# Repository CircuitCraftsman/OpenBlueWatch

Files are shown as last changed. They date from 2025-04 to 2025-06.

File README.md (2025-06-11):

# OpenBlueWatch
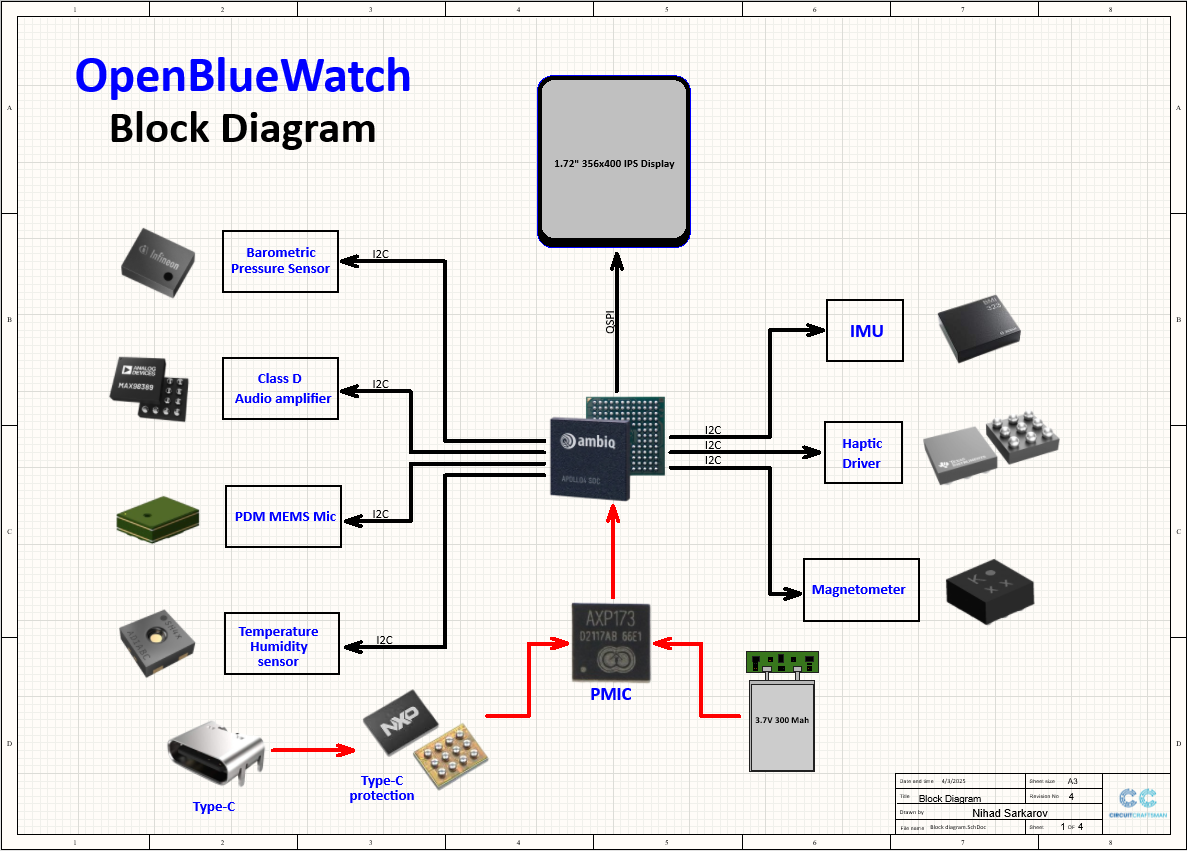
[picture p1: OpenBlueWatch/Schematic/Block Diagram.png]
OpenBlueWatch


Open-source smart watch design in Altium Designer. The smartwatch is based on the Apollo 4 Blue Plus SoC. It incorporates a pressure sensor, an inertial measurement unit, a magnetometer, a temperature and humidity sensor, a MEMS microphone, a haptic driver, and a Class D amplifier. Additionally, power management is based on the AXP173 PMIC. The device can be programmed with the JLINK adapter. 

# Contents
- [Used Tools](#Used-Tools)
- [Specs](#Specs)
- [Schematic](#Schematic)
- [Layout](#Layout)
- [3D Views](#3D-Views)
- [Future Work](#Future-Work)

# Used Tools
    
- Altium Designer

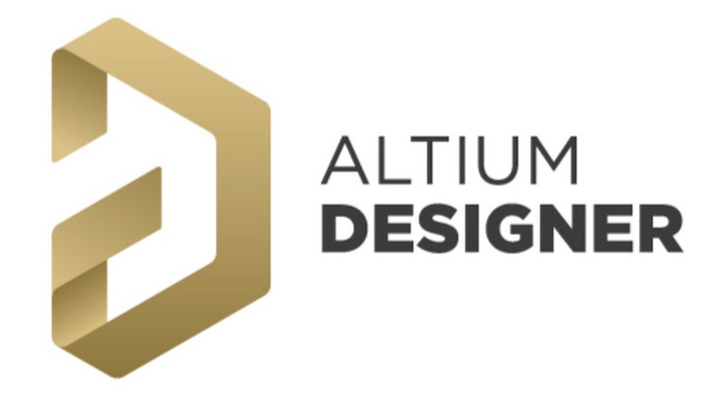
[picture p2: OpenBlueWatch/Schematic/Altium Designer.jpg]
Altium Designer


Altium Designer (AD) is a software package for printed circuit board (PCB) design and electronic design automation. It was developed by the American software company Altium Limited. Altium Designer was formerly known as Protel.

- Saturn PCB Toolkit

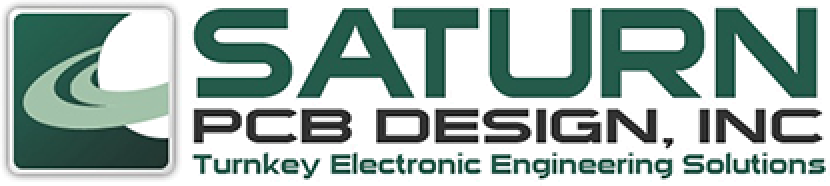
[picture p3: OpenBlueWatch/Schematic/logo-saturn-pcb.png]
Saturn PCB Toolkit


The Saturn PCB Toolkit is the best freeware resource for PCB-related calculations. It incorporates many features that PCB designers and engineers regularly need, like the current capacity of a PCB trace, via current, differential pairs, and much more.

# Specs

  • Bluetooth Low Energy (BLE) 5.4
  
  • Real-time Time Clock
  
  • Environmental sensors
  
  • Smart Power Management
  
  • Type-C charger

# Schematic 

**MCU**

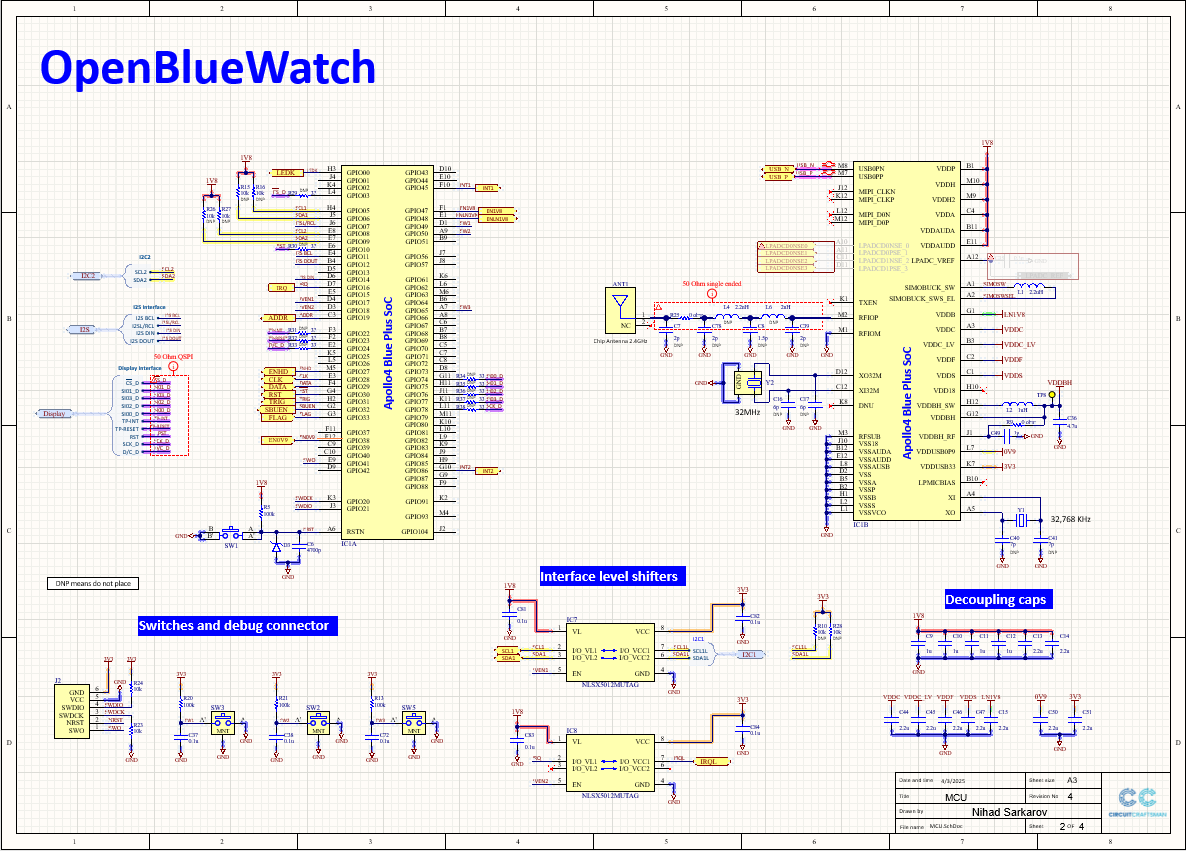
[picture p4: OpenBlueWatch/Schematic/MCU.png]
MCU


**Sensors**

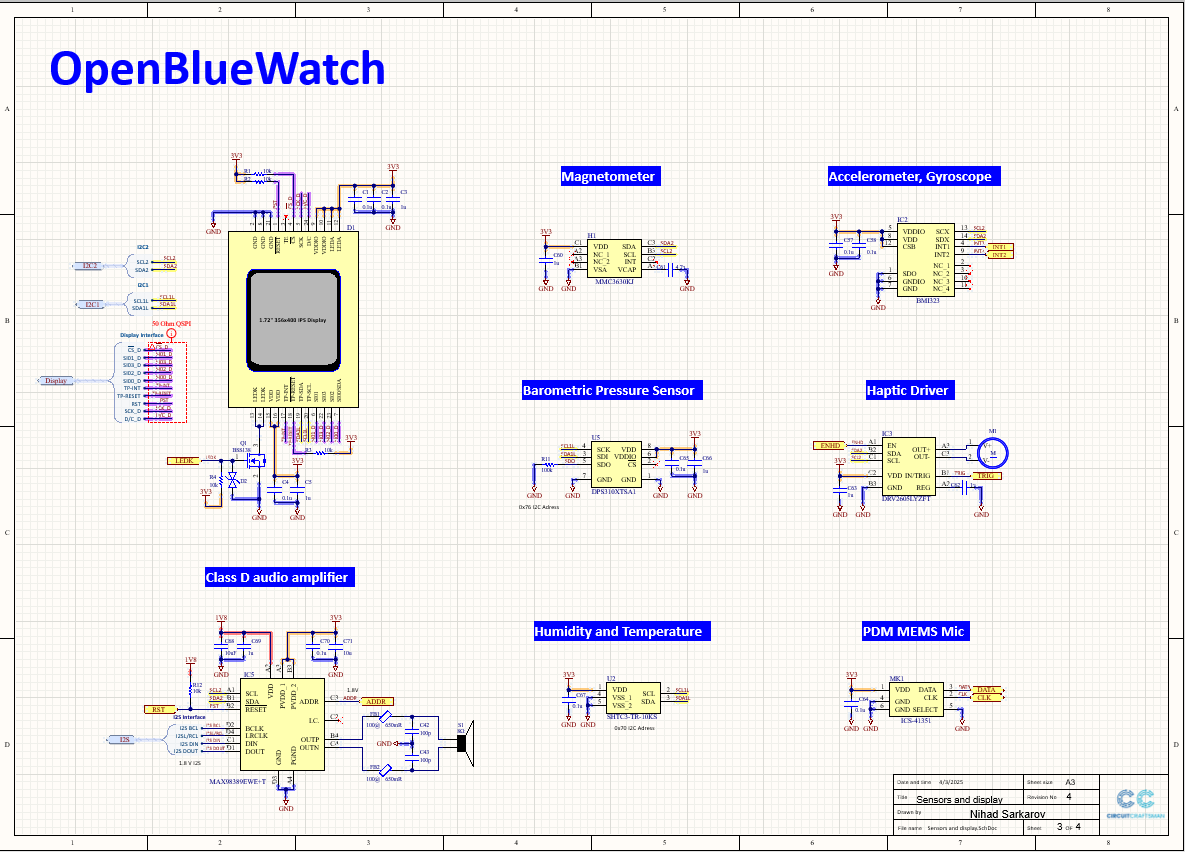
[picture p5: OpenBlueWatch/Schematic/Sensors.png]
Sensors


**Power**

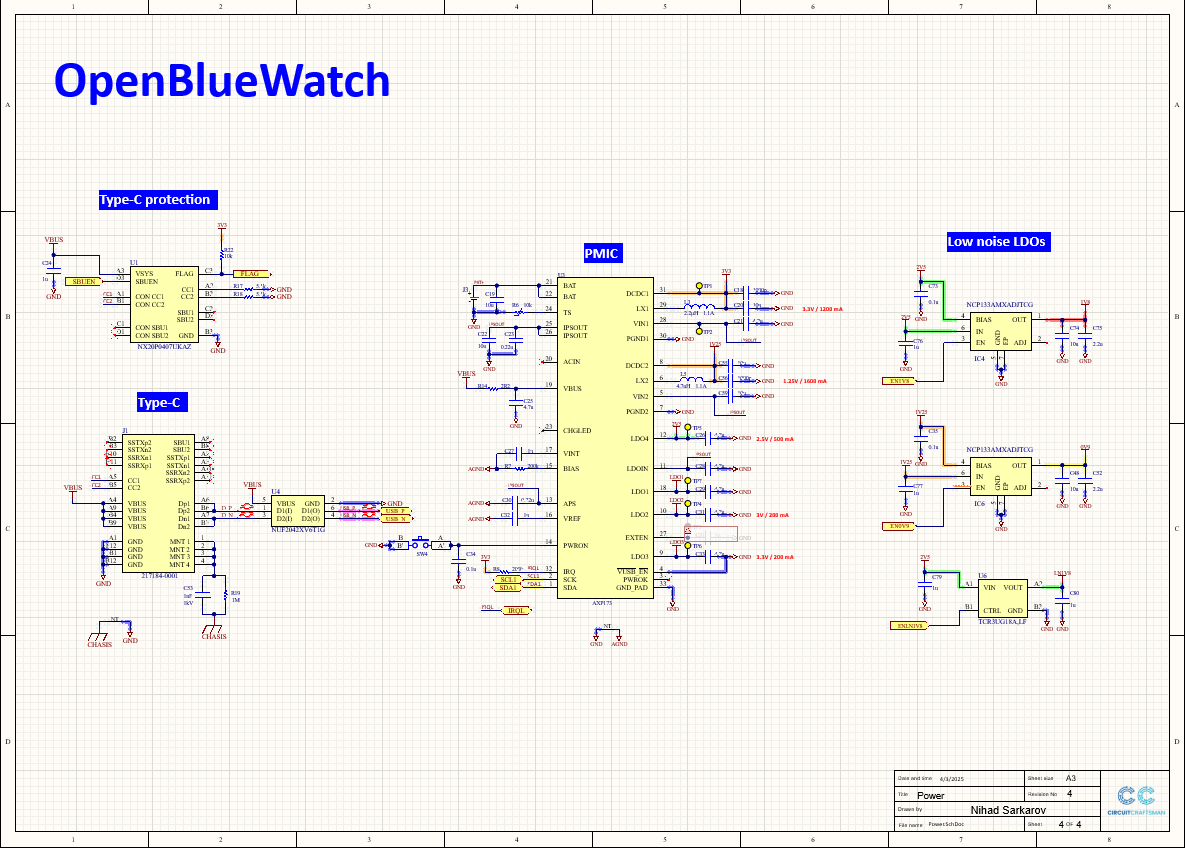
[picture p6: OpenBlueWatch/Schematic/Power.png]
Power


# Layout

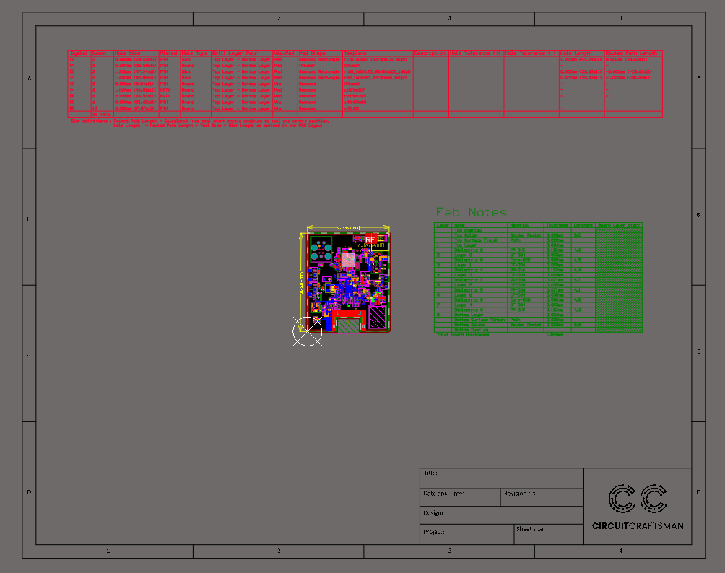
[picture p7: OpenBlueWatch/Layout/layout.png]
Layout


# 3D views

**Front View (Version 2)**

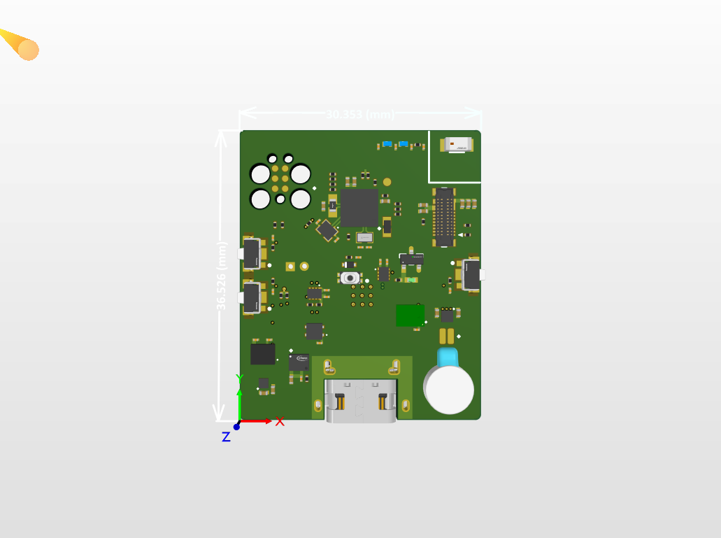
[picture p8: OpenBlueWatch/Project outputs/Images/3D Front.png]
Front


**Front View (Version 1)**

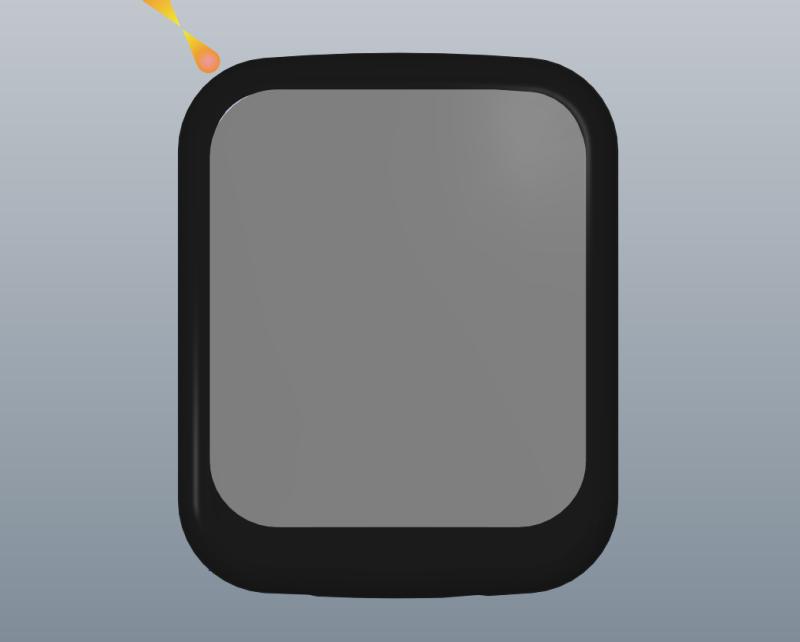
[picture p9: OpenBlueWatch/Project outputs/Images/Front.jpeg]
Front (Version 1)


**Front without display (Version 1)**

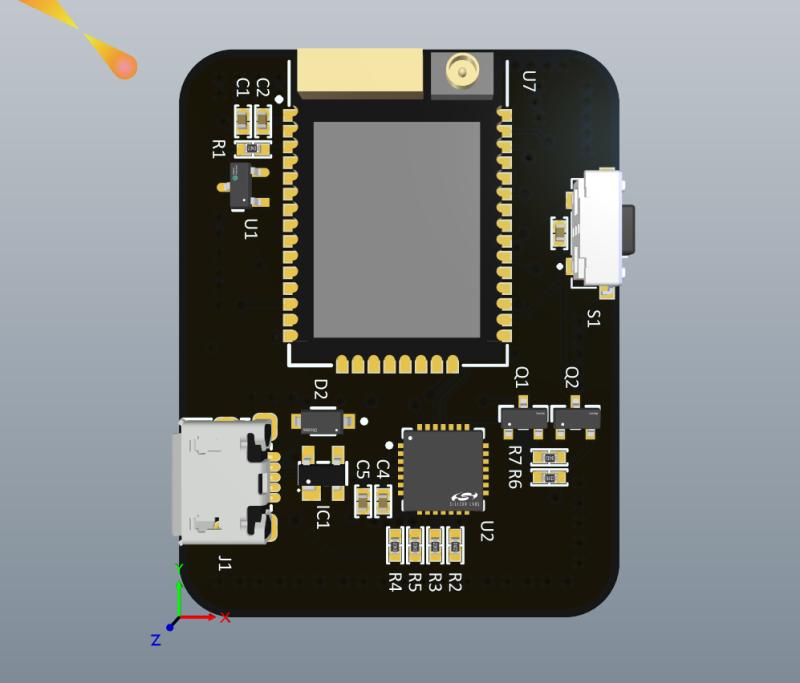
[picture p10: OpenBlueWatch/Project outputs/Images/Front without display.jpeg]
Front without display (Version 1)


**Back (Version 1)**

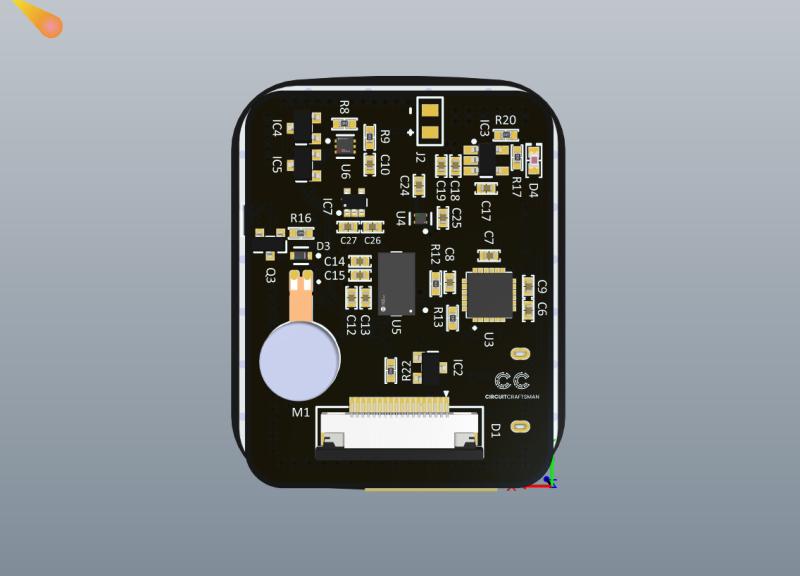
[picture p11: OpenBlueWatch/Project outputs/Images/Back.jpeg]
Back (Version 1)


# Future Work

  • The device will be designed using another layer stackup
  
  • NFC feature will be added
  
  • Another power management solution will be used

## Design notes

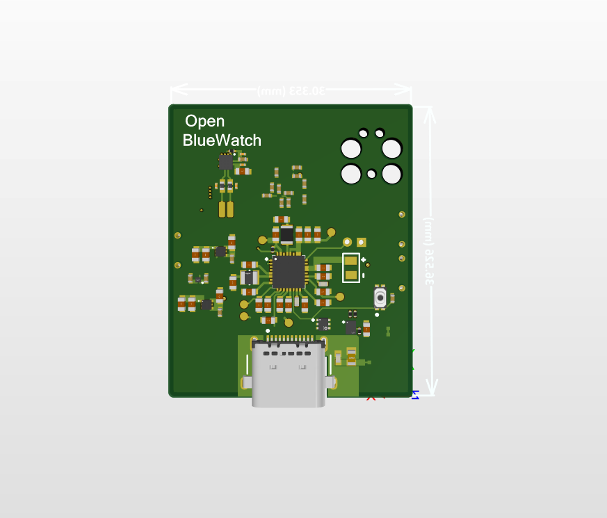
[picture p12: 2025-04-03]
OpenBlueWatch/Project outputs/Images/3D Back.png

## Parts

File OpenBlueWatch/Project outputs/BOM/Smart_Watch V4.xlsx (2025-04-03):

Comment | Description | Designator | Footprint | LibRef | Quantity
2450AT18A0100001E | 2450AT18A0100001E Antenna Chip 2.4GHZ Miniature | ANT1 | FP-2450AT18A0100001E-MFG | CMP-00849-122784405-1 | 1
CC0402KRX7R7BB104 | CAP CER X7R 0402 | C1, C2, C3, C4, C5, C9, C10, C11, C12, C13, C14, C15, C34, C35, C36, C44, C45, C46, C47, C49, C50, C51, C60, C61, C62, C63, C66, C68, C73, C79, C80 | FP-CC0402-IPC_C | CMP-03422-000048-1 | 31
CC0201KRX7R8BB102 | CAP CER X7R 0201 | C6, C7, C8, C16, C17, C37, C38, C39, C40, C41, C42, C43, C57, C58, C64, C65, C67, C69, C70, C72, C78, C81, C82, C83, C84 | FP-CC0201-BA-MFG | CMP-03422-000456-1 | 25
C1608X7R1E105K080AB | Multilayer Ceramic Capacitors 1μF ±10% 25V X7R SMD 0603 | C18, C19, C20, C21, C22, C23, C24, C25, C26, C27, C28, C29, C30, C31, C32, C33, C48, C52, C55, C56, C59, C71, C74, C75, C76, C77 | FP-C1608-080-0_1-MFG | CMP-08246-005723-1 | 26
C0603V102KDRAC7867 | 1000 pF ±10% 1000V (1kV) Ceramic Capacitor X7R 0603 (1608 Metric) | C53 | CAPC1608X90N | C0603V102KDRAC7867 | 1
1.72" 356x400 IPS Display | B2B Connector 24 Pin – In Cell Touch | D1 | CONN-SMD_24P-P0.40_X0400FVS-24-LPSN | 1.72" 356*400 IPS Display | 1
PGB1010402KR | TVS DIODE 12V 250V 0402 | D2 | FP-PGB1-0402-IPC_A | CMP-2000-05189-2 | 1
PESD5V0X1UB,135 | Ultra low capacitance unidirectional ElectroStatic Discharge (ESD) protection diode in a SOD523 (SC-79) ultra small and flat lead Surface-Mounted Device (SMD) plastic package designed to protect one signal line from the damage caused by ESD and other transients.<p> <author>AAL Eindhoven MK</author><hr><p> <img src=http://www.nxp.com/img/NXP_logo.png> | D3 | SOD523 | PESD5V0X1UB,135 | 1
BLM15AG102SN1D | Chip Ferrite Bead, 0402, 1000Ω @ 100MHz, 0.65Ω, 25%, 300mA | FB1, FB2 | FP-BLM15-0_05-IPC_A | CMP-0686-00181-5 | 2
MMC3630KJ | MAGNETIC SENSOR 3-AXIS 1.2X1.2MM | H1 | BGA8C40P3X3_120X120X57 | MMC3630KJ | 1
AMA4B2KP-KXR | ARM® Cortex®-M4F System On Chip (SOC) IC Apollo4 Blue Plus 192MHz 131-BGA (4.7x4.7) | IC1 | BGA131C35P12X12_470X470X90 | AMA4B2KP-KXR | 1
BMI323 | Accelerometer, Gyroscope, 6 Axis Sensor I2C, I3C, SPI Output | IC2 | BMI323 | BMI323 | 1
DRV2605LYZFT | Motor Driver Power MOSFET I2C 9-DSBGA | IC3 | BGA9C50P3X3_144X144X62 | DRV2605LYZFT | 1
NCP133AMXADJTCG | Integrated Circuit | IC4, IC6 | NCP133AMX110TCG | NCP133AMXADJTCG | 2
MAX98389EWE+T | Amplifier IC 1-Channel (Mono) Class D 16-WLP (1.64x1.79) | IC5 | BGA16C40P4X4_179X164X69 | MAX98389EWE+T | 1
NLSX5012MUTAG | Voltage Level Translator Bidirectional 1 Circuit 2 Channel 100Mbps 8-UDFN (1.8x1.2) | IC7, IC8 | NLSX5012MUTAG | NLSX5012MUTAG | 2
217184-0001 | MID-MOUNT DUAL ROWS SMT 24POS -T | J1 | FP-217184-0001-MFG | CMP-04767-000027-1 | 1
8.06.16_J-LINK_6-PIN_NEEDLE_ADAPTER | J-LINK 6-PIN NEEDLE ADAPTER | J2 | SEGGER_8.06.16_J-LINK_6-PIN_NEEDLE_ADAPTER | 8.06.16_J-LINK_6-PIN_NEEDLE_ADAPTER | 1
Battery connector | JST-PH 2.0MM | J3 | JST-PH 2.0MM | Battery connector | 1
MBKK1608T2R2M | Ind Power Wirewound 2.2uH 20% 1MHz Metal 520mA 0603 Embossed T/R | L1 | INDC1608X100N | MBKK1608T2R2M | 1
DFE18SAN1R0ME0L | FIXED IND 1UH 1.6A 144 MOHM SMD | L2 | FP-DFE18SAN_E0-IPC_A | CMP-06042-016331-1 | 1
BRC2012T2R2MD | Wire-Wound Chip Power Inductor, 2.2 uH, +/- 20%, -40 to 105 degC, 2-Pin SMD (0805), RoHS, Tape and Reel | L3 | INDC2013X140X50LL20T20 | CMP-2000-05964-1 | 1
LQW15AN3N9B00D | Wire Wound RF Inductor 3.9nH ±0.1nH 750mA 0.07Ω 0402 (1005) | L4, L6 | FP-LQW15AN_00-W0_6-0_1-MFG | CMP-06042-000827-1 | 2
LQM2MPN4R7MG0L | Multilayer Type Inductor for Power Lines, 0806 (2016), 4.7μH, 20%, 0.175Ω, 1.1A | L5 | FP-LQM2MPN_G0-MFG | CMP-06042-016483-1 | 1
NFP-WS0625 | 6mm Brushless Coin Vibration Motor 2.5mm Type Motor | M1 | NFP-WS0625 | NFP-WS0625 | 1
ICS-41351 | 50 Hz ~ 20 kHz Digital, PDM Microphone MEMS (Silicon) Omnidirectional (-26dB ±1dB @ 94dB SPL) Solder Pads | MK1 | MIC_ICS-41351 | ICS-41351 | 1
BSS138 | MOSFET N-CH 50V 220MA SOT-23 | Q1 | FP-318-08-IPC_B | CMP-07173-000101-1 | 1
CRCW02010000Z0ED | Chip Resistor, 0 Ohm, 0.05 W, -55 to 155 degC, 0201 (0603 Metric), RoHS, Tape and Reel | R1, R2, R3, R4, R5, R8, R9, R10, R11, R12, R13, R15, R16, R17, R18, R20, R21, R22, R23, R24, R25, R26, R27, R28, R29, R30, R31, R32, R33, R34, R35, R36, R37, R38 | RESC0603X28X15LL5T05 | CMP-2004-00001-2 | 34
NTSD1XH103FPB30 | NTC Thermistors 10kΩ ±1% Current 0.12mA Radial | R6 | FP-NTSD1_FPB30-MFG | CMP-06022-000009-1 | 1
CRCW040222R0FKED |  | R7, R14 | RESC1005X40X25LL05T05 | CMP-2002-08382-1 | 2
ERJ-2GEJ105X |  | R19 | RESC1005X40X25ML05T05 | CMP-1011-00146-2 | 1
CMS-15118D-L100 | 8 Ohms Low Profile Speaker 700 mW 425 Hz ~ 10 kHz Top Rectangular | S1 | CMS-15118D-L100 | CMS-15118D-L100 | 1
EVP-BB2A9B000 | SWITCH TACTILE SPST-NO 0.02A 15V | SW1, SW4 | FP-EVP-BB2A9B000-MFG | CMP-05618-000013-1 | 2
EVP-AKE31A | 3.8MM X 1.9MM / 1.6N / 0.12MM ST | SW2, SW3, SW5 | FP-EVP-AKE31A-MFG | CMP-05618-000005-1 | 3
Test point | 1mm x 1mm round pad for testing purposes | TP1, TP2, TP4, TP5, TP6, TP7, TP8 | Test point | Test point | 7
NX20P0407UKAZ | USB TYPE-C CC1/2 SBU1/2 PROT IC | U1 | FP-SOT1390-7-IPC_A | CMP-10136-000007-1 | 1
SHTC3-TR-10KS | Humidity, Temperature 0 ~ 100% RH I2C ±2% RH 8 s Surface Mount | U2 | SHTC3TR10KS | SHTC3-TR-10KS | 1
AXP173 | PMIC | U3 | QFN40P400X400X55-33N | AXP173 | 1
NUF2042XV6T1G | RC (Pi) EMI Filter 2nd Order Low Pass 2 Channel R = 22Ohms, C = 42pF (Total) SOT-563, SOT-666 | U4 | FP-463A-MFG | CMP-1066-00027-2 | 1
DPS310XTSA1 | Pressure Sensor 4.35PSI ~ 17.4PSI (30kPa ~ 120kPa) Absolute 24 b 8-VFLGA | U5 | FP-PG-VLGA-8-MFG | CMP-32885-000002-2 | 1
TCR3UG18A,LF | IC REG LINEAR 1.8V 300MA 4WCSP-F | U6 | FP-WCSP4F-IPC_C | CMP-35871-000003-1 | 1
ABS06-32.768KHZ-1-T | CRYSTAL 32.7680KHZ 12.5PF SMD | Y1 | FP-ABS06-MFG | CMP-27762-012387-2 | 1
CX2016DB32000D0WZRC1 | 32 MHz ±25ppm Crystal 8pF 60 Ohms 4-SMD, No Lead | Y2 | CX2016DB32000D0WZRC1 | CX2016DB32000D0WZRC1 | 1

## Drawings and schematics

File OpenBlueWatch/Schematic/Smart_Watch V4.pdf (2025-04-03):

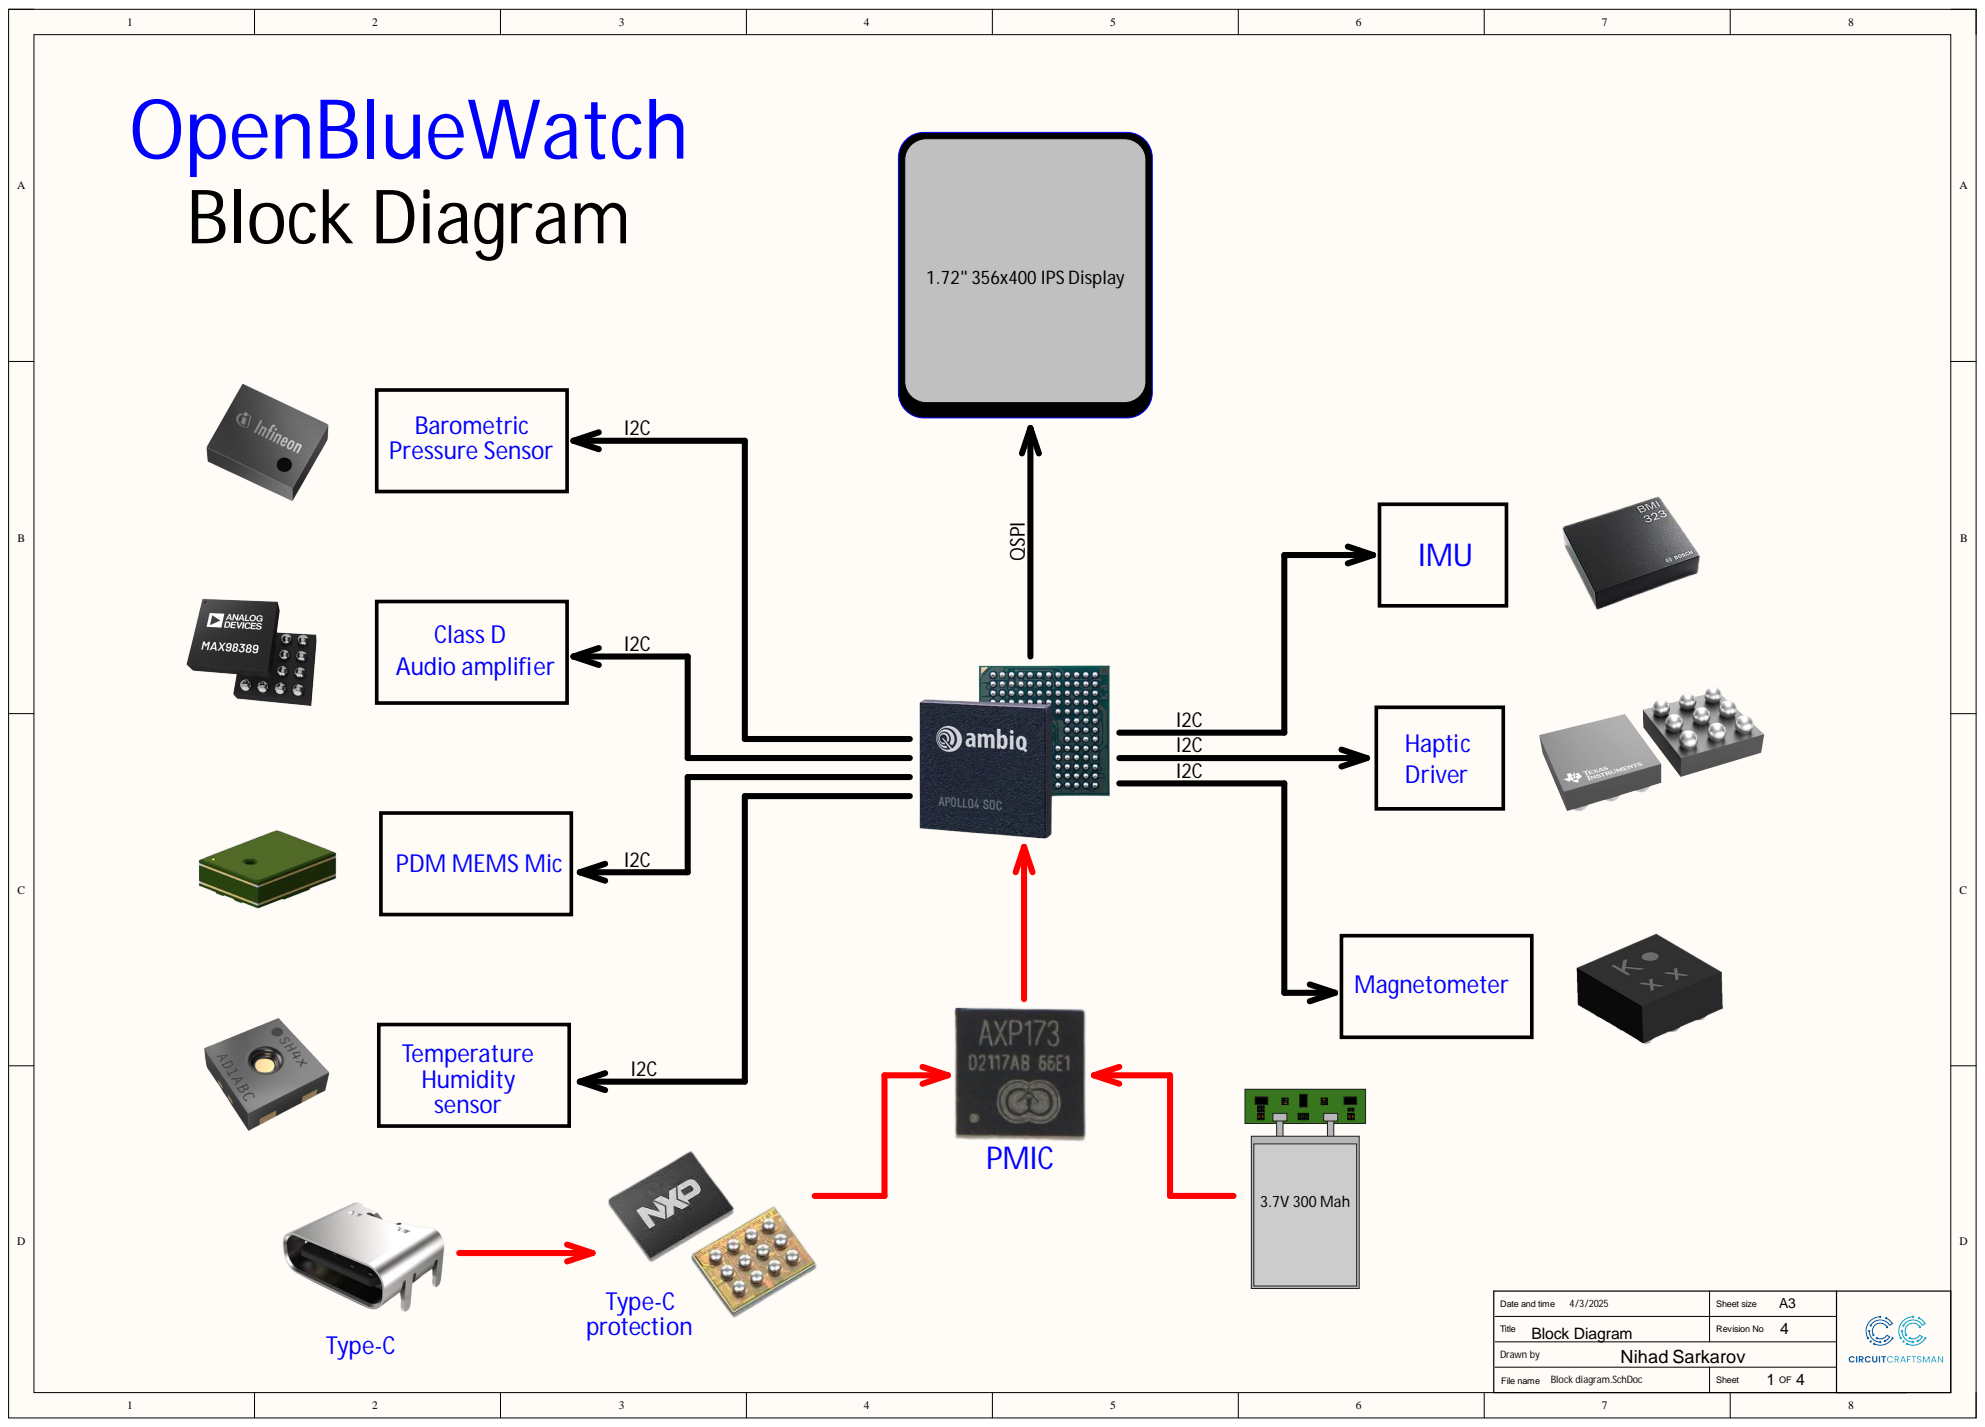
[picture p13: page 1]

Date and time 4/3/2025 | Sheet size A3

Block Diagram Title | 4 Revision No

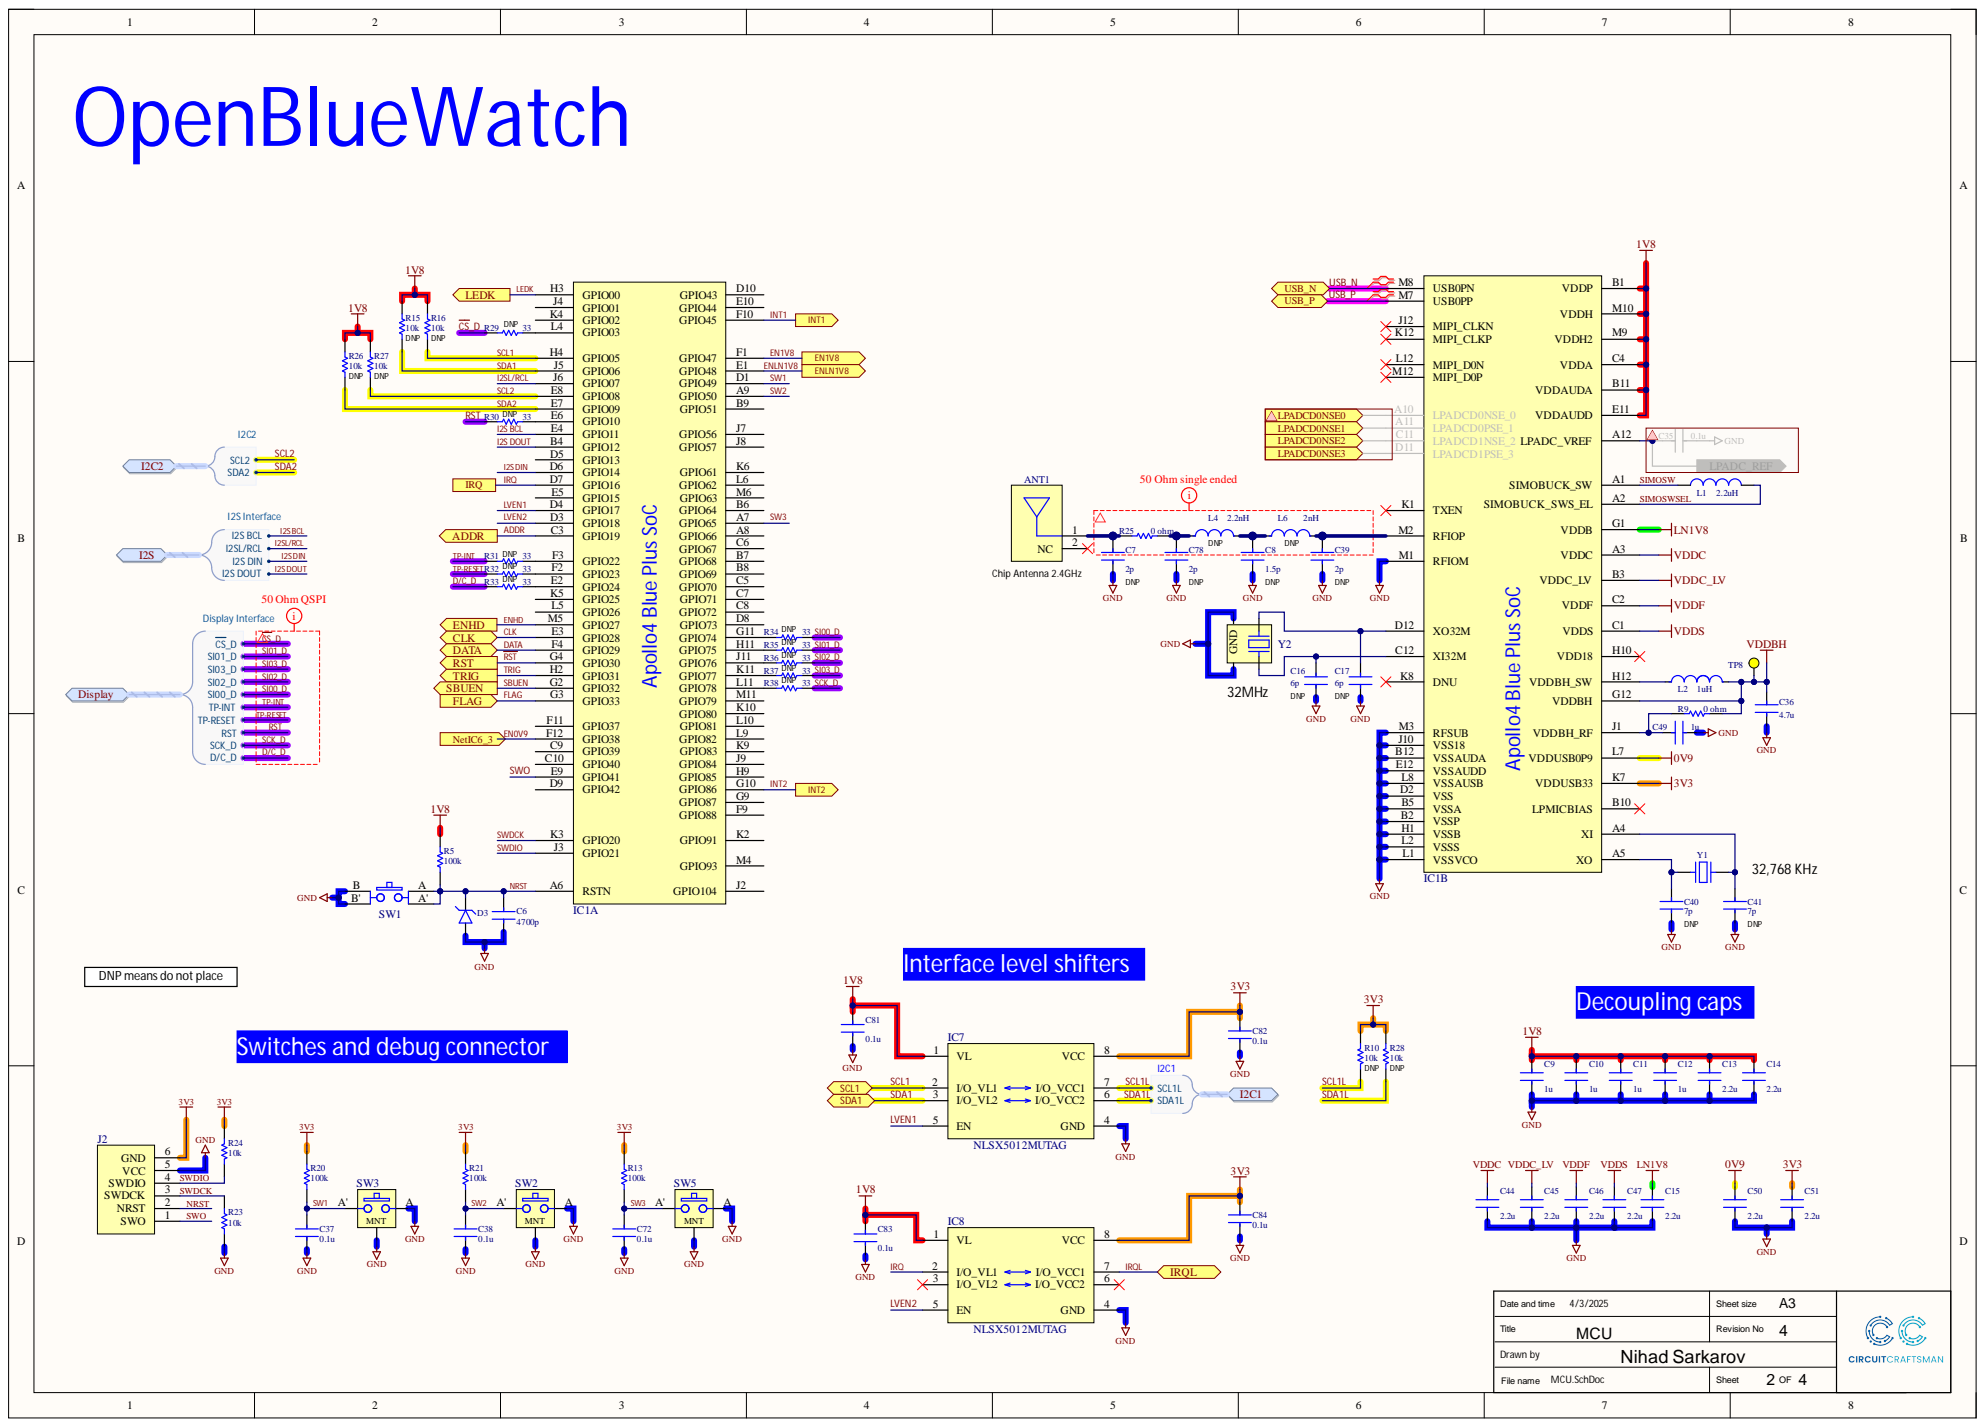
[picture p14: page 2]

DNP means do not place

Switches and debug connector

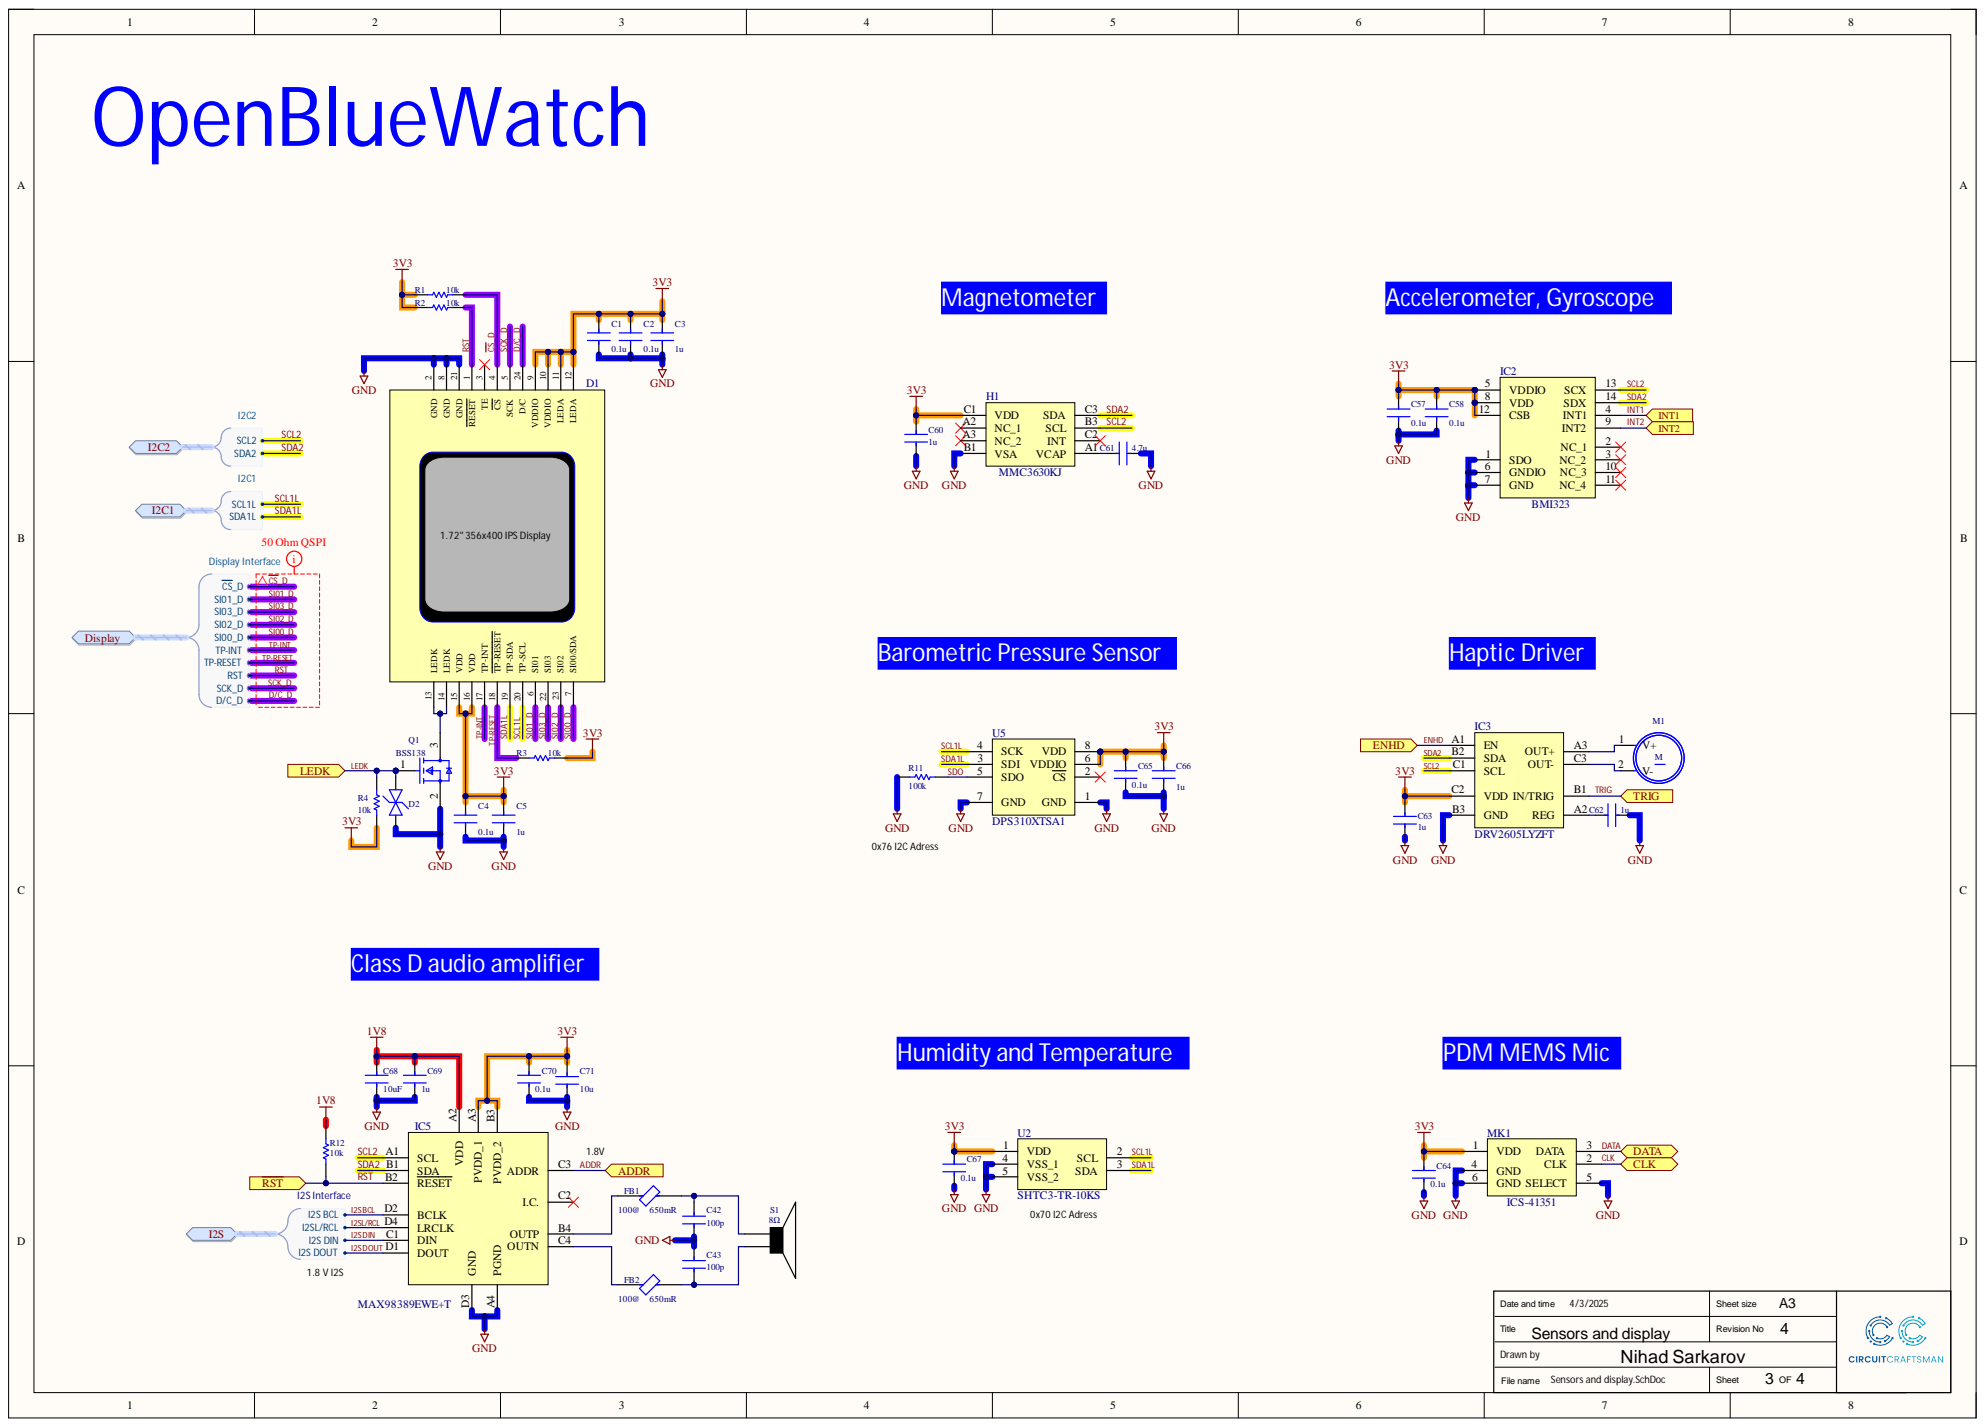
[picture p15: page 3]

Date and time 4/3/2025 | Sheet size A3

Sensors and display Title | 4 Revision No

Sensors and display.SchDoc

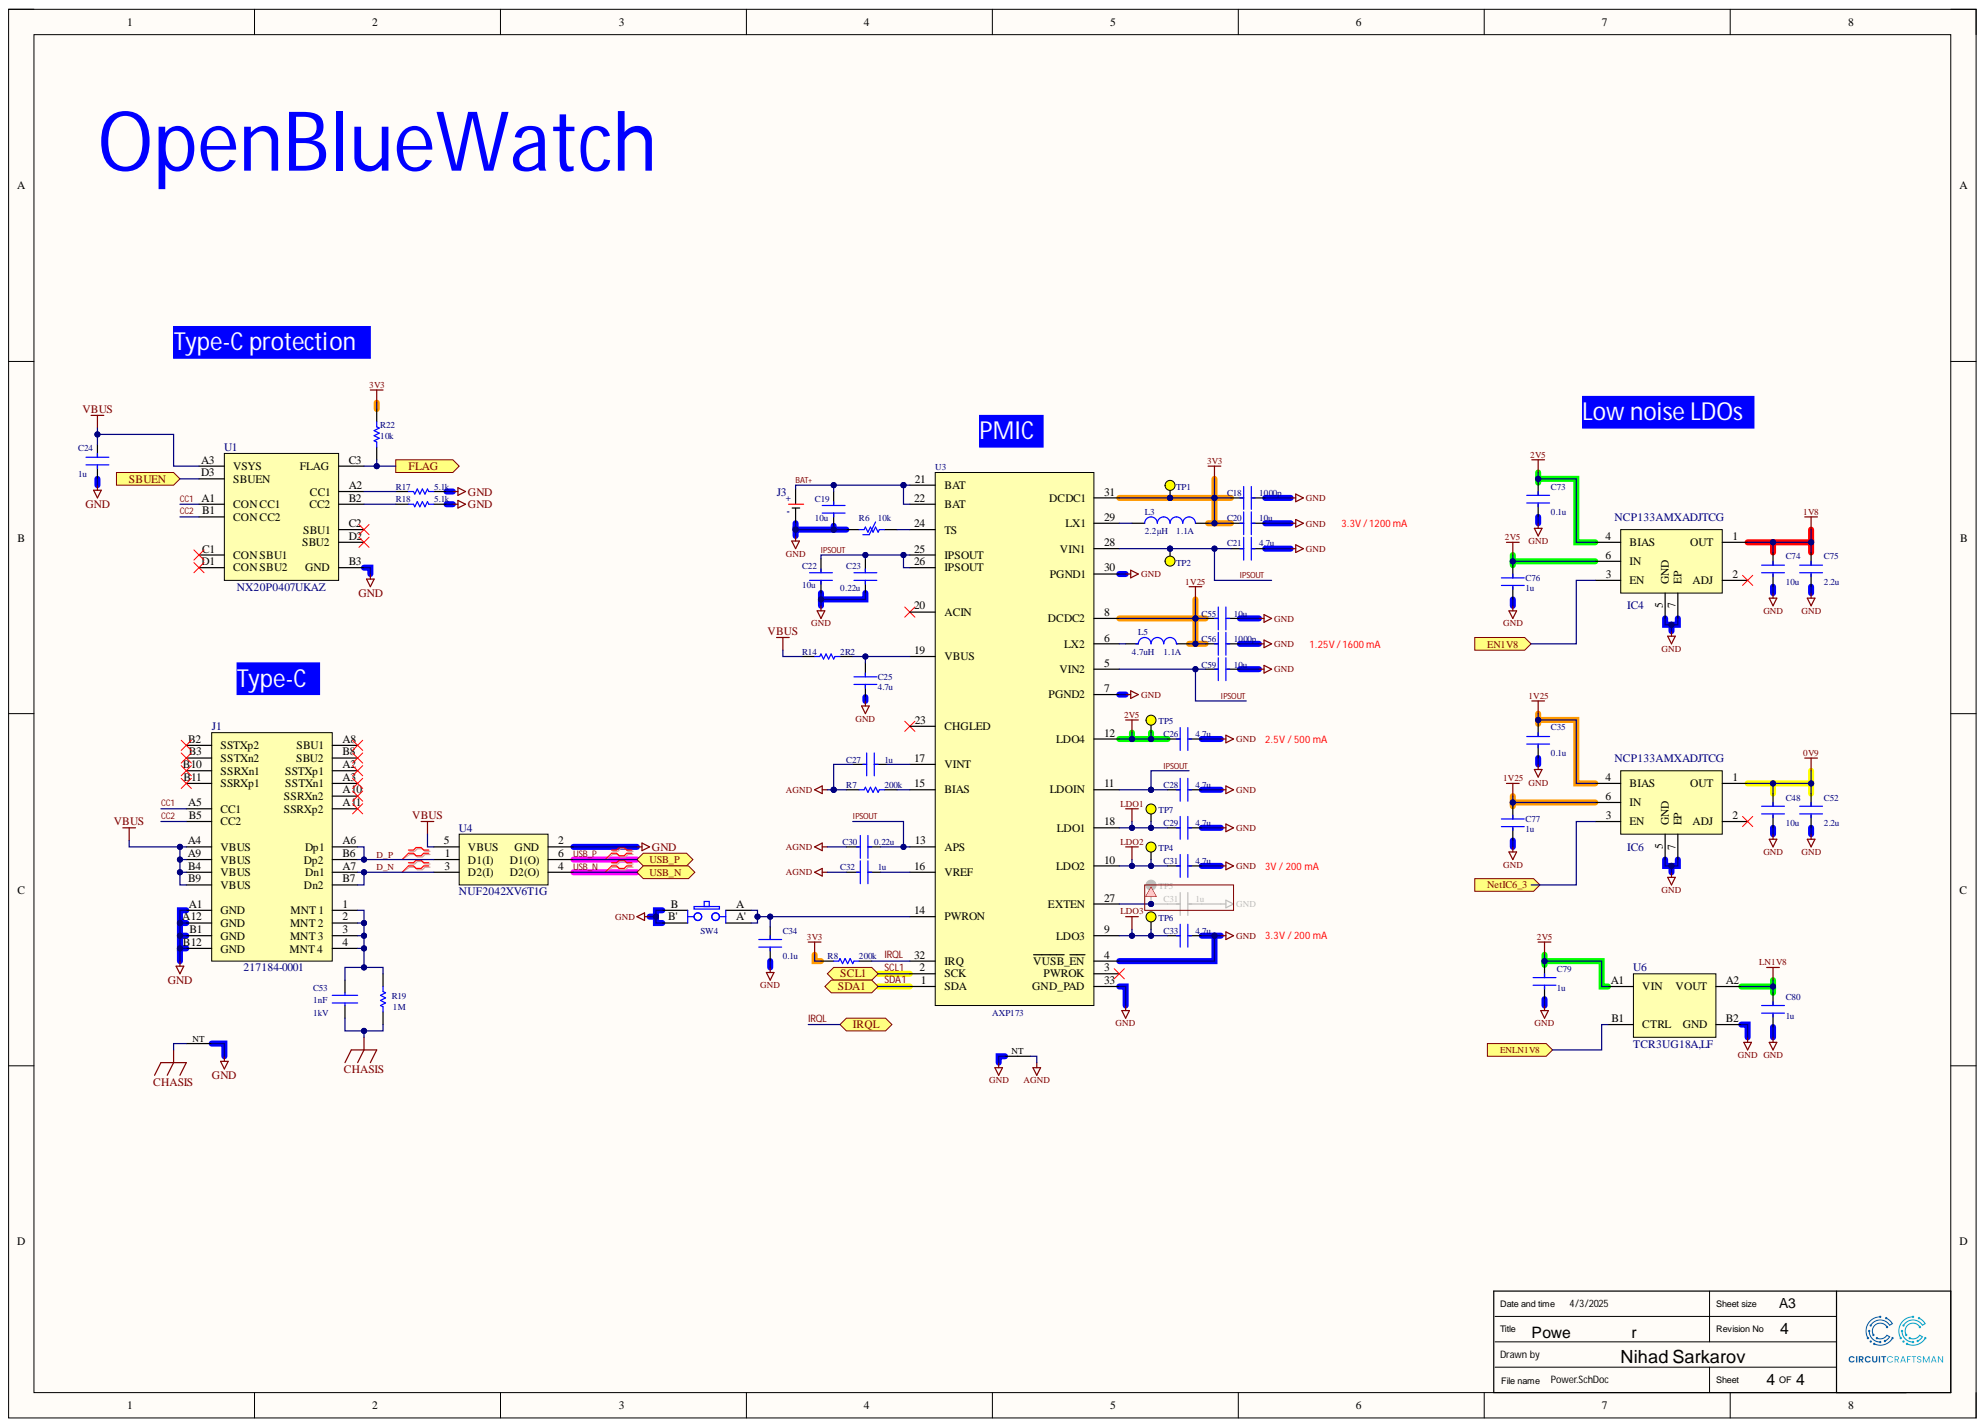
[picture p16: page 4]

T i t l e P owe r | 4 R e v i s i o n N o
